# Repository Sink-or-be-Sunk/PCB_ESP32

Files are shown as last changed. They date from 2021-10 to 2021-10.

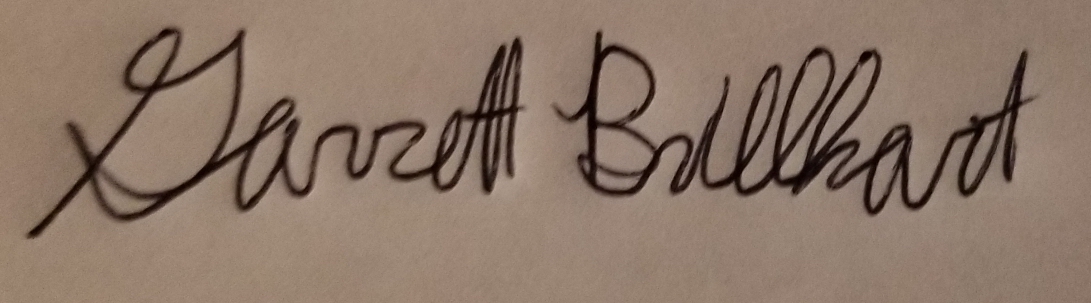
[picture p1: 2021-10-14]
assets/Garrett.jpeg

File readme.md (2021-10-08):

# Sink or be Sunk Hardware

This project contains the KiCAD PCB and auxiliary hardware needed for physical gameplay.

## Helpful Notes

### Nested Sheets

In KiCAD you can use a neat feature to split your project into multiple files. This not only helps to reduce cluter on one single diagram, it also allows for reuse of a common schematic element.

For this project specifically, the Grid.sch file can be reused for both the top (attack) grid and the bottom (ship positioning) grid.

`Hierarchical Labels` - KiCAD allows you to place a label on a nested sheet that can be viewed by the parenet sheet. Ex: you place a label on the STM32 Sheet and you can connect to it from the Main Layout schematic.

- Locate the `Hierarchical Labels` button on the right hand toolbar in kicad to place a label in a child sheet.
  - See section A4 of the STM32 Sheet
- Navigate back to the parent sheet and right click on the child sheet where you jused added the label
- Select the `import sheet pins` option
  - NOTE that you will have to do this for every new pin that you add to the child sheet, kinda repetative if you have a bunch of heirarchical labels...

`ESP32 Reference Design` - Adafruit produced a reference/dev board for the ESP32. They have great documentation on the device and are generous enough to include images of their schematic. This is a good place to start for our design. See the [Adafruit Website](https://learn.adafruit.com/adafruit-huzzah32-esp32-feather/downloads) for details.

#### PCB Updates to PCB_ESP32

I added a new branch with a new file "Main", containing all updated symbol and footprint libraries. There appears to be an issue between KiCad's footprint libraries in Version 4 and 5.0+. I believe I resolved this issue, let me know if you're still missing access to certain footprints. 

Other than that, I think this is a start. One great thing about our Main PCB is that the dimensions on it are much more flexible than the Row PCBs. If we need more room, we can make the board longer (wider will start to run into the grid). 

Some things to think about:
- USB to Serial: Where is the most convenient place for the plug? 
- What are the repercussions of placing the speaker next to the motor? 
- Where on the exterior of the board should the speaker knob/reset button go, without being bumped or in the way?

There's plenty of work left, but this is the start!

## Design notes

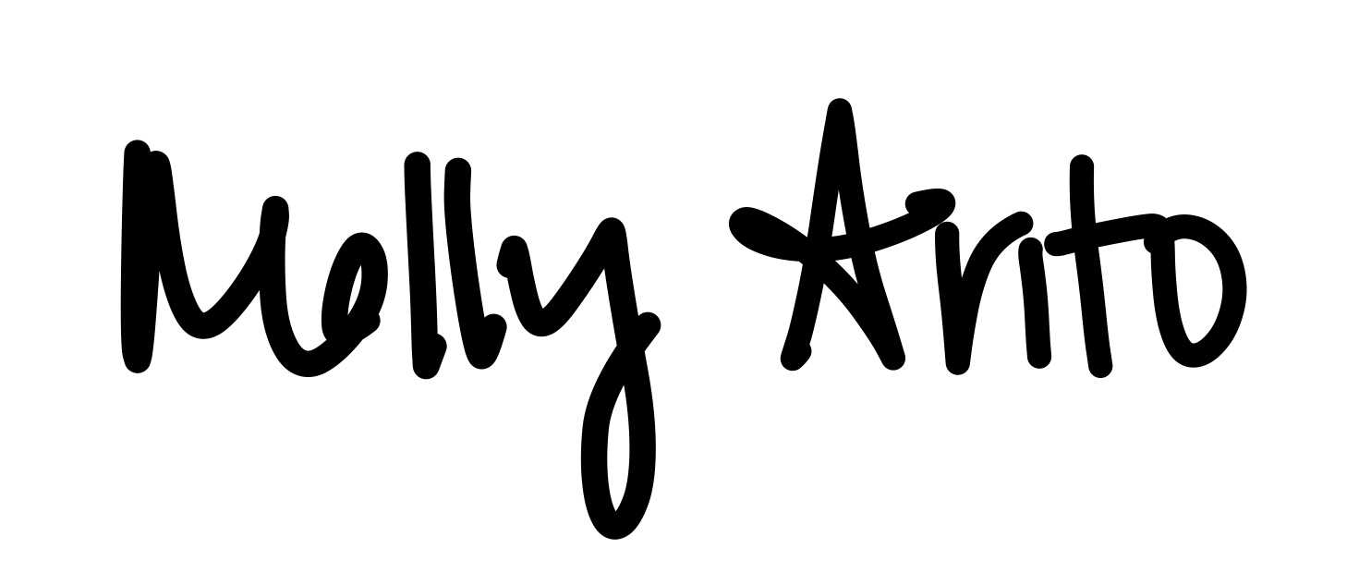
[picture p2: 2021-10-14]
assets/Molly.PNG

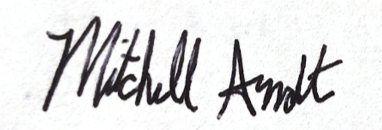
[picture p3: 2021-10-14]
assets/Mitch.png

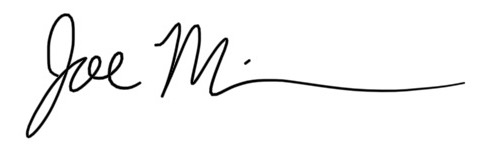
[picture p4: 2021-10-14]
assets/Joe.jpeg

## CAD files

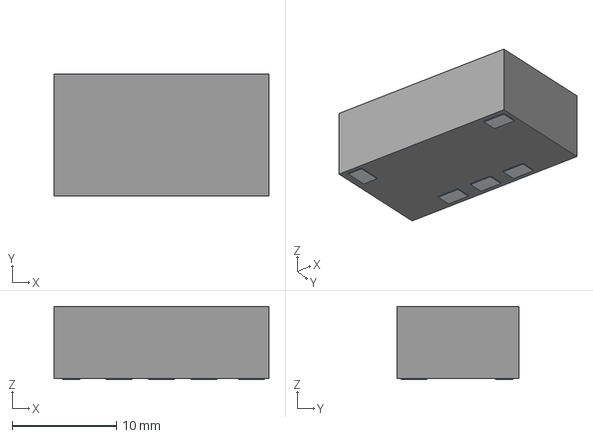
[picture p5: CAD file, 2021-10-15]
models/DNT04S0A0S03NFA.stp
20.6 x 11.7 x 7.00 mm
Pins

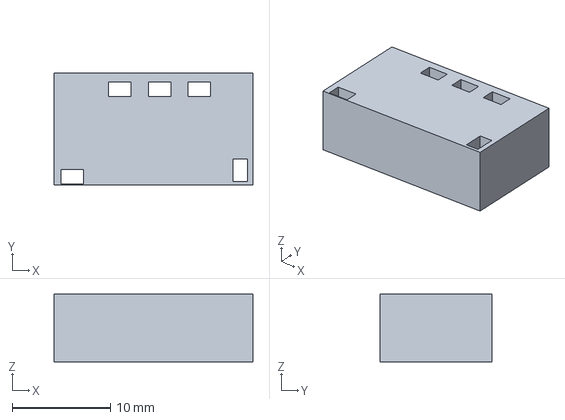
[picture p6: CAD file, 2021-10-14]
models/Regulator.step
20.3 x 11.4 x 6.90 mm

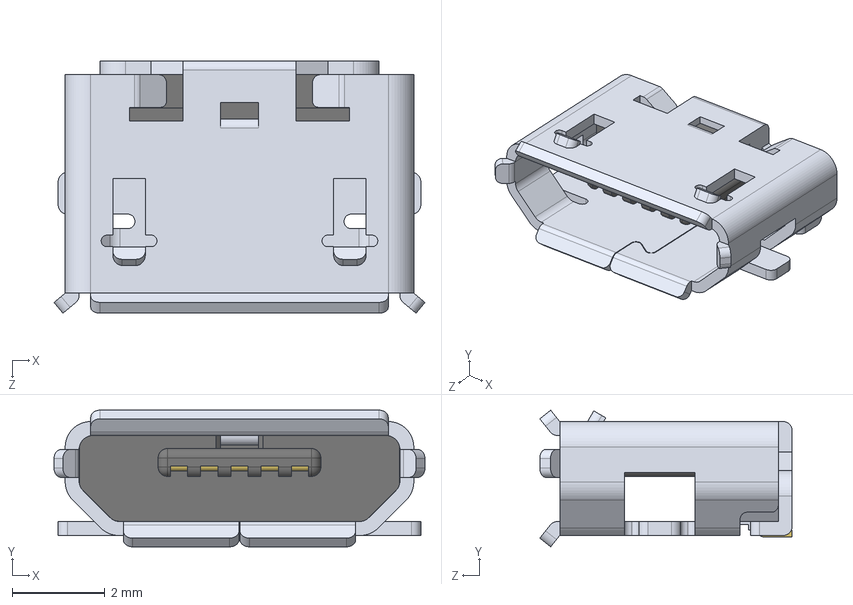
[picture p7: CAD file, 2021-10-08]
models/micro_usb.STEP
7.98 x 2.94 x 5.43 mm

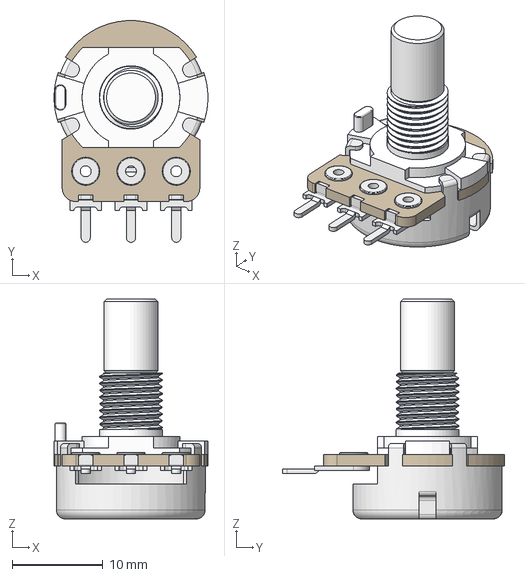
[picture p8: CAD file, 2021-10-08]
models/POT.step
17.0 x 24.5 x 24.3 mm

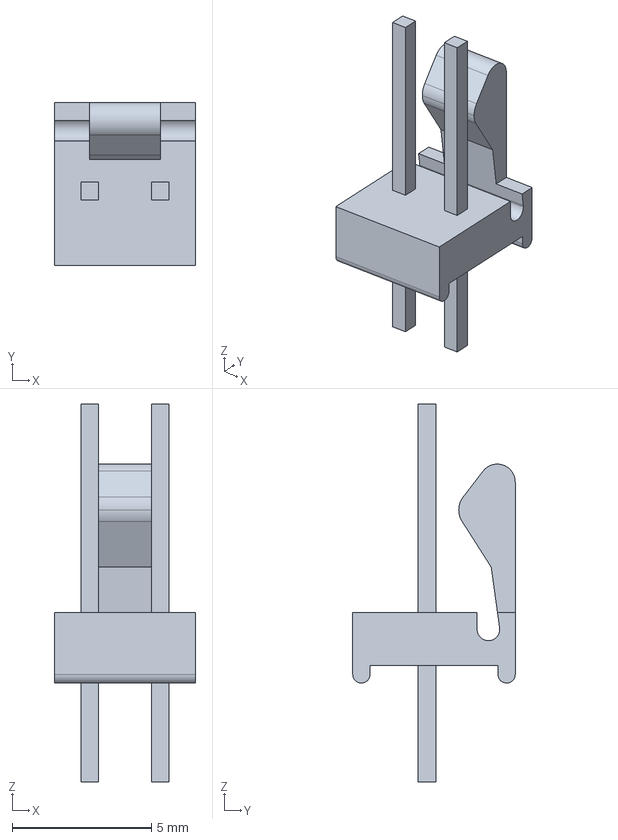
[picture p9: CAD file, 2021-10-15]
models/640456-2.step
5.08 x 5.84 x 13.6 mm

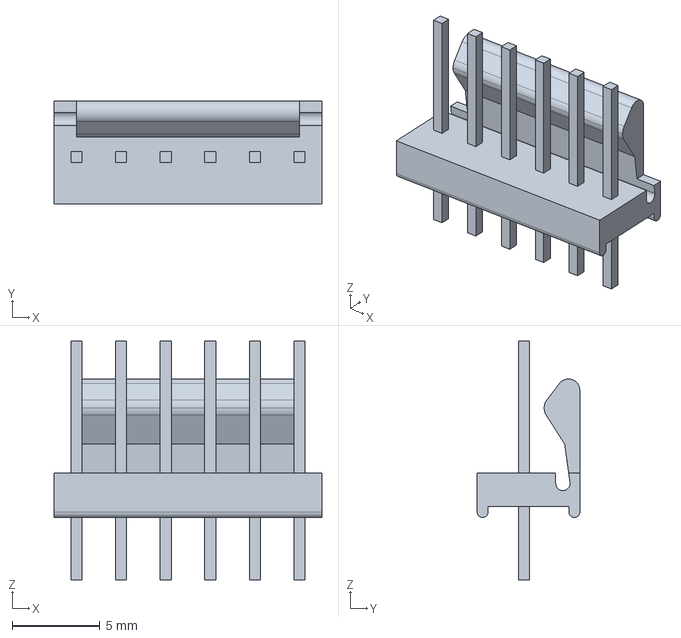
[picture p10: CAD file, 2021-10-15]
models/640456-6.step
15.2 x 5.84 x 13.6 mm

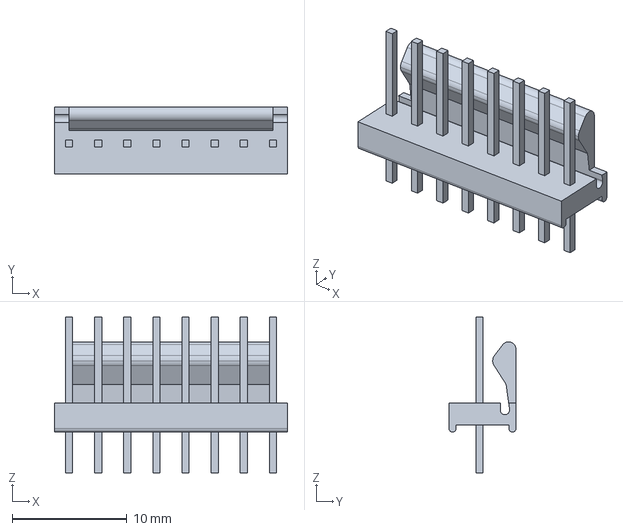
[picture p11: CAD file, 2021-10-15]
models/640456-8.step
20.3 x 5.84 x 13.6 mm

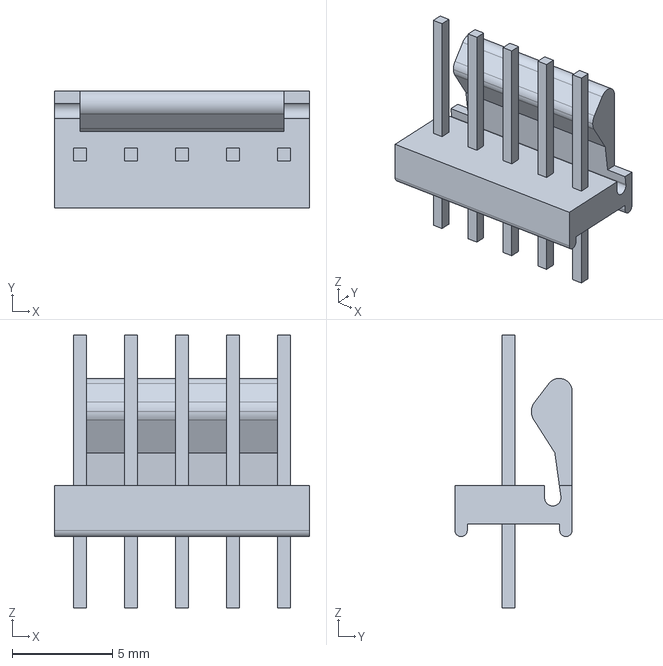
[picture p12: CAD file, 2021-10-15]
models/640456-5.step
12.7 x 5.84 x 13.6 mm

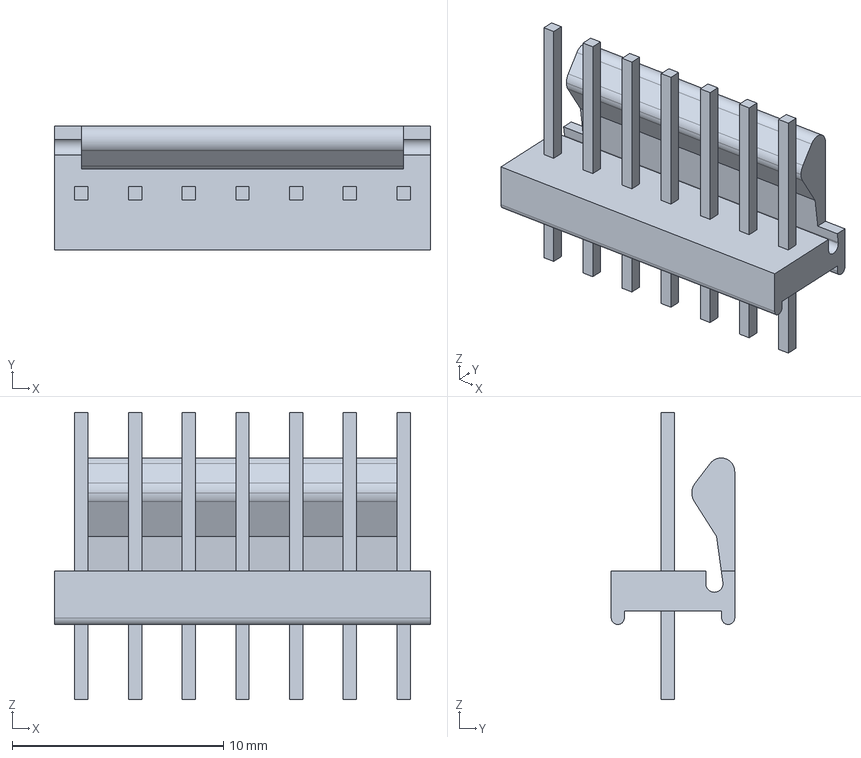
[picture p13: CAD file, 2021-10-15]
models/640456-7.step
17.8 x 5.84 x 13.6 mm

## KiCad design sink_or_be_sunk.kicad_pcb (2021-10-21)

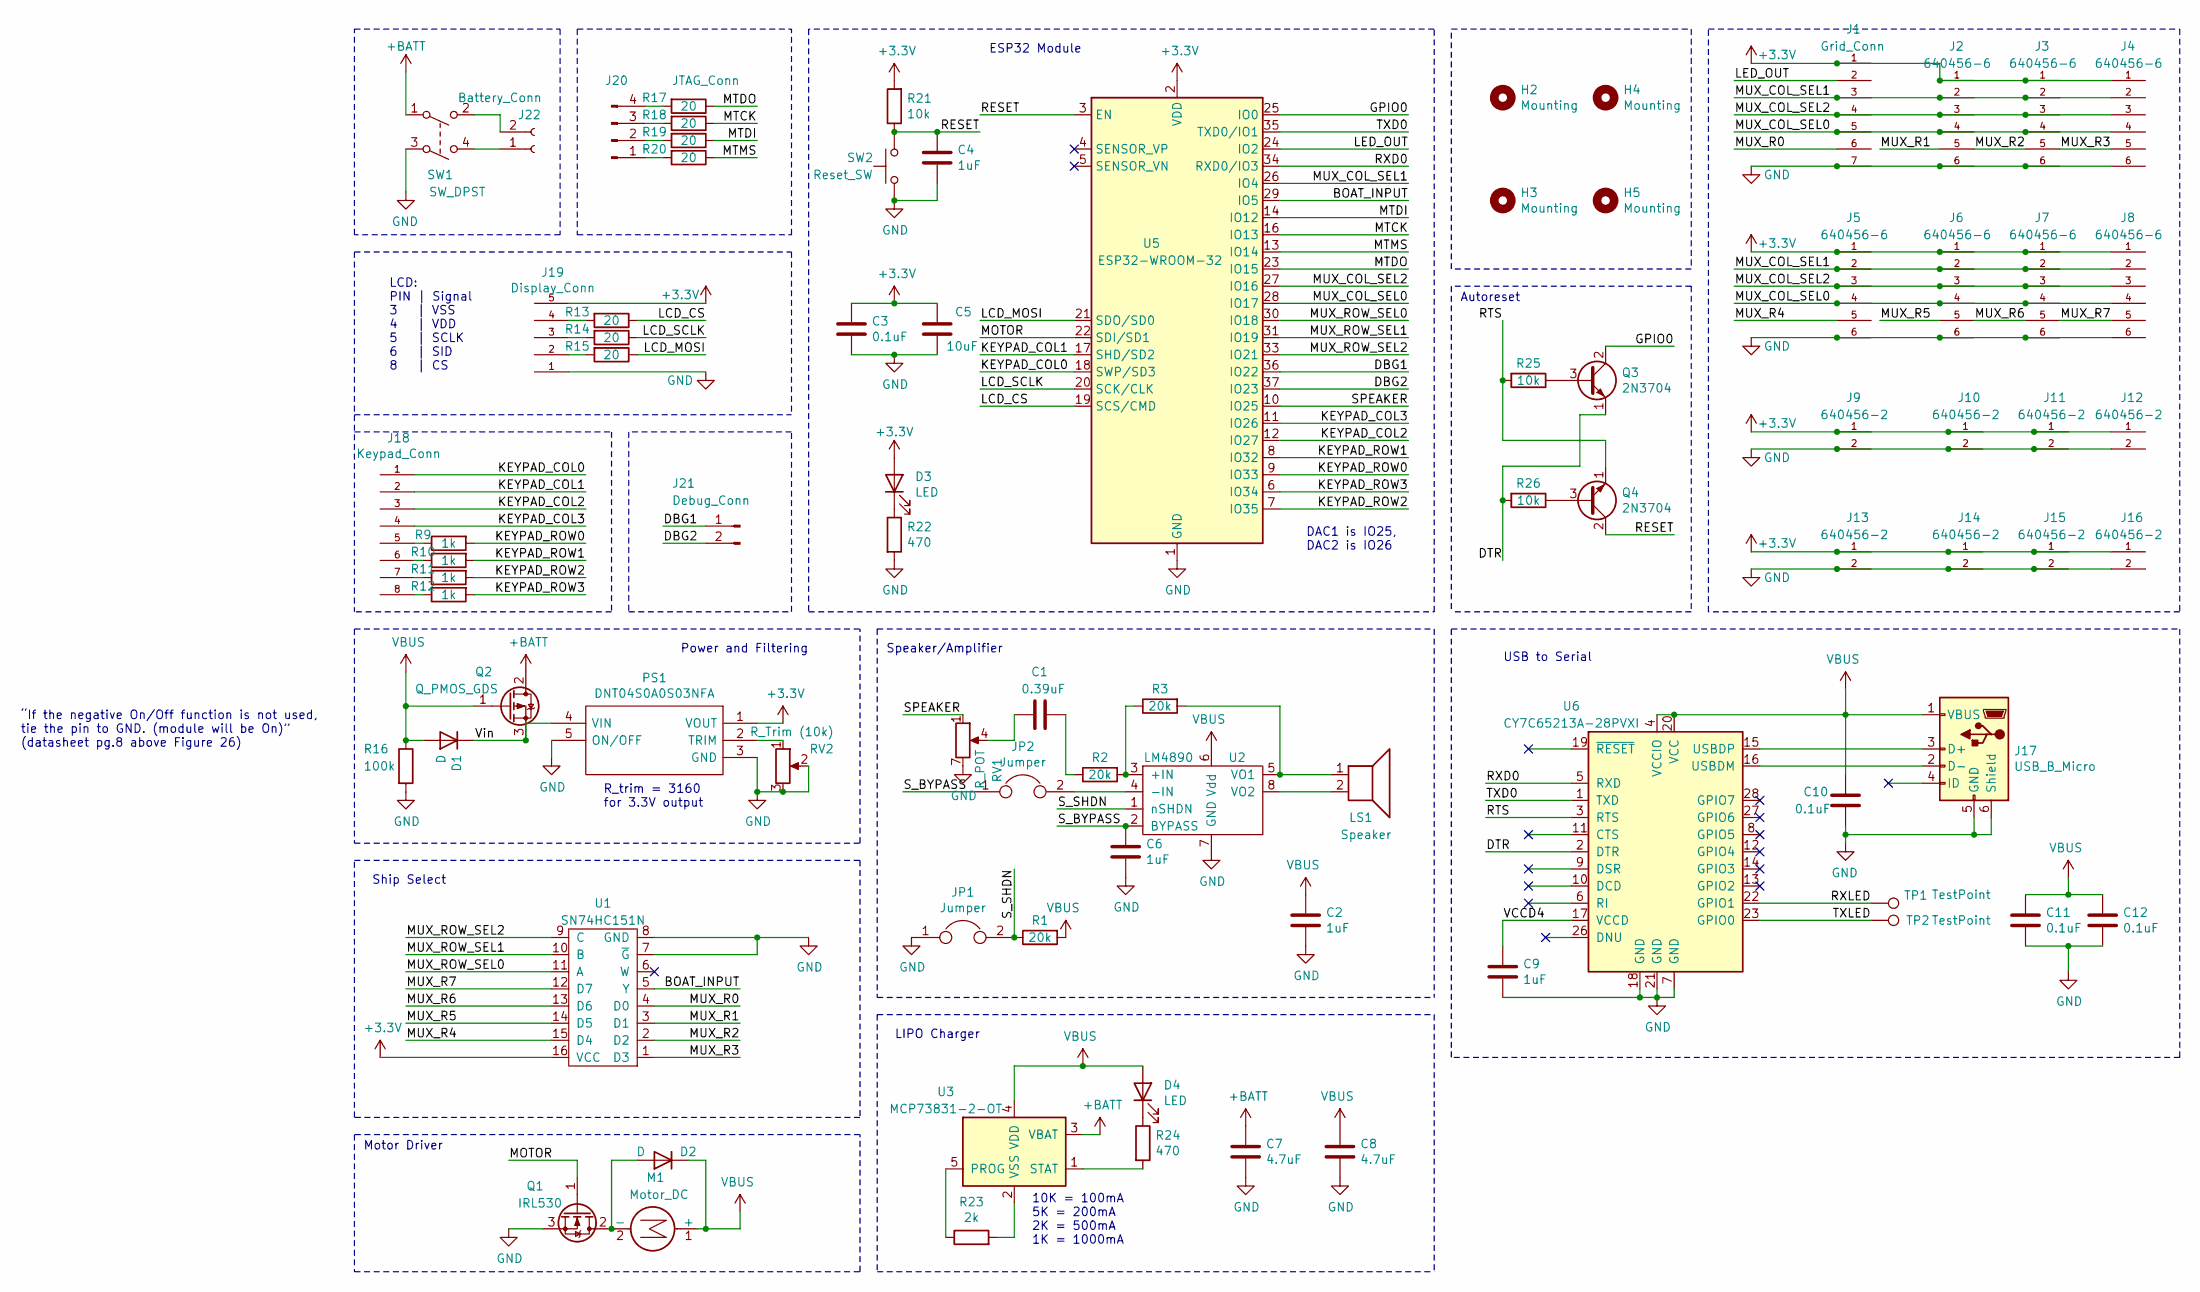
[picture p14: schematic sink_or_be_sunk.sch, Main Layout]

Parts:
C1: 0.39uF; C_0805_2012Metric_Pad1.18x1.45mm_HandSolder
C2, C4, C6: 1uF; C_0805_2012Metric_Pad1.18x1.45mm_HandSolder
C3, C10, C11, C12: 0.1uF; C_0805_2012Metric_Pad1.15x1.40mm_HandSolder
C5: 10uF; CP_Radial_D5.0mm_P2.50mm
C7, C8: 4.7uF; CP_Radial_D5.0mm_P2.50mm
C9: 1uF; C_0805_2012Metric_Pad1.15x1.40mm_HandSolder
D1, D2: D; D_A-405_P7.62mm_Horizontal
D3, D4: LED; LED_D3.0mm
H2, H3, H4, H5: Mounting; MountingHole_3.2mm_M3
J1: Grid_Conn; TE_640456-7
J2, J3, J4, J5, J6, J7, J8: 640456-6; TE_640456-6
J9, J10, J11, J12, J13, J14, J15, J16: 640456-2; TE_640456-2
J17: USB_B_Micro; USB_Micro_B_Female_Vert_1051330001
J18: Keypad_Conn; TE_640456-8
J19: Display_Conn; TE_640456-5
J20: JTAG_Conn; PinHeader_1x04_P2.54mm_Vertical
J21: Debug_Conn; PinHeader_1x02_P2.54mm_Vertical
J22: Battery_Conn; JST_PH_S2B-PH-K_1x02_P2.00mm_Horizontal
JP1, JP2: Jumper; PinHeader_1x02_P2.54mm_Vertical
LS1: Speaker; TE_640456-2
M1: Motor_DC; TE_640456-2
PS1: DNT04S0A0S03NFA; Mouser Part Number 108-DNT04S0A0S03NFA
Q1: IRL530; TO-220-3_Vertical
Q2: Q_PMOS_GDS; TO-251-3-1EP_Horizontal_TabDown
Q3, Q4: 2N3704; TO-92
R1, R2, R3: 20k; R_0805_2012Metric_Pad1.20x1.40mm_HandSolder
R9, R10, R11: 1k; R_0805_2012Metric_Pad1.20x1.40mm_HandSolder
R12: 1k; R_0805_2012Metric_Pad1.15x1.40mm_HandSolder
R13, R14, R15, R17, R18, R19, R20: 20; R_0805_2012Metric_Pad1.20x1.40mm_HandSolder
R16: 100k; R_0805_2012Metric_Pad1.15x1.40mm_HandSolder
R21, R25, R26: 10k; R_0805_2012Metric_Pad1.20x1.40mm_HandSolder
R22: 470; R_0805_2012Metric_Pad1.20x1.40mm_HandSolder
R23: 2k; R_0805_2012Metric_Pad1.15x1.40mm_HandSolder
R24: 470; R_0805_2012Metric_Pad1.15x1.40mm_HandSolder
RV1: R_POT; PinHeader_1x07_P2.54mm_Vertical
RV2: R_Trim (10k); Potentiometer_Bourns_3266Y_Vertical
SW1: SW_DPST; PinHeader_1x04_P2.54mm_Vertical
SW2: Reset_SW; PinHeader_1x02_P2.54mm_Vertical
TP1, TP2: TestPoint; TestPoint_Plated_Hole_D2.0mm
U1: SN74HC151N; DIP-16_W10.16mm
U2: LM4890; TSSOP-8_3x3mm_P0.65mm
U3: MCP73831-2-OT; SOT-23-5
U5: ESP32-WROOM-32
U6: CY7C65213A-28PVXI; SSOP-28_5.3x10.2mm_P0.65mm

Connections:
+3V3: C3.1, C5.1, D3.2 (A), J1.1, J2.1, J3.1, J4.1, J5.1, J6.1, J7.1, J8.1, J9.1, J10.1, J11.1, J12.1, J13.1, J14.1, J15.1, J16.1, J19.5, PS1.1 (VOUT), R21.2, U1.16 (VCC), U5.2 (VDD)
+BATT: C7.1, Q2.2 (D), SW1.1, U3.3 (VBAT)
/BOAT_INPUT: U1.5 (Y), U5.29 (IO5)
/DBG1: J21.1, U5.36 (IO22)
/DBG2: J21.2, U5.37 (IO23)
/DTR: Q3.1 (E), R26.2, U6.2 (DTR)
/GPIO0: Q3.2 (C), U5.25 (IO0)
/KEYPAD_COL0: J18.1, U5.18 (SWP/SD3)
/KEYPAD_COL1: J18.2, U5.17 (SHD/SD2)
/KEYPAD_COL2: J18.3, U5.12 (IO27)
/KEYPAD_COL3: J18.4, U5.11 (IO26)
/KEYPAD_ROW0: R9.2, U5.9 (IO33)
/KEYPAD_ROW1: R10.2, U5.8 (IO32)
/KEYPAD_ROW2: R11.2, U5.7 (IO35)
/KEYPAD_ROW3: R12.2, U5.6 (IO34)
/LCD_CS: R13.1, U5.19 (SCS/CMD)
/LCD_MOSI: R15.1, U5.21 (SDO/SD0)
/LCD_SCLK: R14.1, U5.20 (SCK/CLK)
/LED_OUT: J1.2, U5.24 (IO2)
/MOTOR: Q1.1 (G), U5.22 (SDI/SD1)
/MTCK: R18.1, U5.16 (IO13)
/MTDI: R19.1, U5.14 (IO12)
/MTDO: R17.1, U5.23 (IO15)
/MTMS: R20.1, U5.13 (IO14)
/MUX_COL_SEL0: J1.5, J2.4, J3.4, J4.4, J5.4, J6.4, J7.4, J8.4, U5.28 (IO17)
/MUX_COL_SEL1: J1.3, J2.2, J3.2, J4.2, J5.2, J6.2, J7.2, J8.2, U5.26 (IO4)
/MUX_COL_SEL2: J1.4, J2.3, J3.3, J4.3, J5.3, J6.3, J7.3, J8.3, U5.27 (IO16)
/MUX_R0: J1.6, U1.4 (D0)
/MUX_R1: J2.5, U1.3 (D1)
/MUX_R2: J3.5, U1.2 (D2)
/MUX_R3: J4.5, U1.1 (D3)
/MUX_R4: J5.5, U1.15 (D4)
/MUX_R5: J6.5, U1.14 (D5)
/MUX_R6: J7.5, U1.13 (D6)
/MUX_R7: J8.5, U1.12 (D7)
/MUX_ROW_SEL0: U1.11 (A), U5.30 (IO18)
/MUX_ROW_SEL1: U1.10 (B), U5.31 (IO19)
/MUX_ROW_SEL2: U1.9 (C), U5.33 (IO21)
/RESET: C4.1, Q4.2 (C), R21.1, SW2.2, U5.3 (EN)
/RTS: Q4.1 (E), R25.2, U6.3 (RTS)
/RXD0: U5.34 (RXD0/IO3), U6.5 (RXD)
/RXLED: TP1.1, U6.22 (GPIO1)
/SPEAKER: RV1.1, U5.10 (IO25)
/S_BYPASS: C6.1, JP2.1, U2.2 (BYPASS)
/S_SHDN: JP1.2, R1.1, U2.1 (nSHDN)
/TXD0: U5.35 (TXD0/IO1), U6.1 (TXD)
/TXLED: TP2.1, U6.23 (GPIO0)
/VCCD4: C9.1, U6.17 (VCCD)
/Vin: D1.1 (K), PS1.4 (VIN), Q2.3 (S)
GND: C2.2, C3.2, C4.2, C5.2, C6.2, C7.2, C8.2, C9.2, C10.2, C11.2, C12.2, J1.7, J2.6, J3.6, J4.6, J5.6, J6.6, J7.6, J8.6, J9.2, J10.2, J11.2, J12.2, J13.2, J14.2, J15.2, J16.2, J17.5 (GND), J17.6 (Shield), J19.1, JP1.1, PS1.3 (GND), PS1.5 (ON/OFF), Q1.3 (S), R16.2, R22.2, RV1.7, RV2.2, RV2.3, SW1.3, SW2.1, U1.7 (~G), U1.8 (GND), U2.7 (GND), U5.1 (GND), U5.15 (GND), U5.38 (GND), U5.39 (GND), U6.7 (GND), U6.18 (GND), U6.21 (GND)
unnamed: C1.1, RV1.4
unnamed: C1.2, R2.1
unnamed: D2.2 (A), M1.2 (-), Q1.2 (D)
unnamed: D3.1 (K), R22.1
unnamed: D4.1 (K), R24.1
unnamed: J17.2 (D-), U6.16 (USBDM)
unnamed: J17.3 (D+), U6.15 (USBDP)
unnamed: J18.5, R9.1
unnamed: J18.6, R10.1
unnamed: J18.7, R11.1
unnamed: J18.8, R12.1
unnamed: J19.2, R15.2
unnamed: J19.3, R14.2
unnamed: J19.4, R13.2
unnamed: J20.1, R20.2
unnamed: J20.2, R19.2
unnamed: J20.3, R18.2
unnamed: J20.4, R17.2
unnamed: J22.1, SW1.4
unnamed: J22.2, SW1.2
unnamed: JP2.2, U2.4 (-IN)
unnamed: LS1.1, R3.2, U2.5 (VO1)
unnamed: LS1.2, U2.8 (VO2)
unnamed: PS1.2 (TRIM), RV2.1
unnamed: Q3.3 (B), R25.1
unnamed: Q4.3 (B), R26.1
unnamed: R2.2, R3.1, U2.3 (+IN)
unnamed: R23.1, U3.5 (PROG)
unnamed: R23.2, U3.2 (VSS)
unnamed: R24.2, U3.1 (STAT)
VBUS: C2.1, C8.1, C10.1, C11.1, C12.1, D1.2 (A), D2.1 (K), D4.2 (A), J17.1 (VBUS), M1.1 (+), Q2.1 (G), R1.2, R16.1, U2.6 (Vdd), U3.4 (VDD), U6.4 (VCCIO), U6.20 (VCC)

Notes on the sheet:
LCD: PIN | Signal 3 | VSS 4 | VDD 5 | SCLK 6 | SID 8 | CS
10K = 100mA 5K = 200mA 2K = 500mA 1K = 1000mA
USB to Serial
ESP32 Module
Motor Driver
Autoreset
LIPO Charger
Ship Select
Speaker/Amplifier
DAC1 is IO25, DAC2 is IO26
“If the negative On/Off function is not used, tie the pin to GND. (module will be On)” (datasheet pg.8 above Figure 26)
R_trim = 3160 for 3.3V output
Power and Filtering

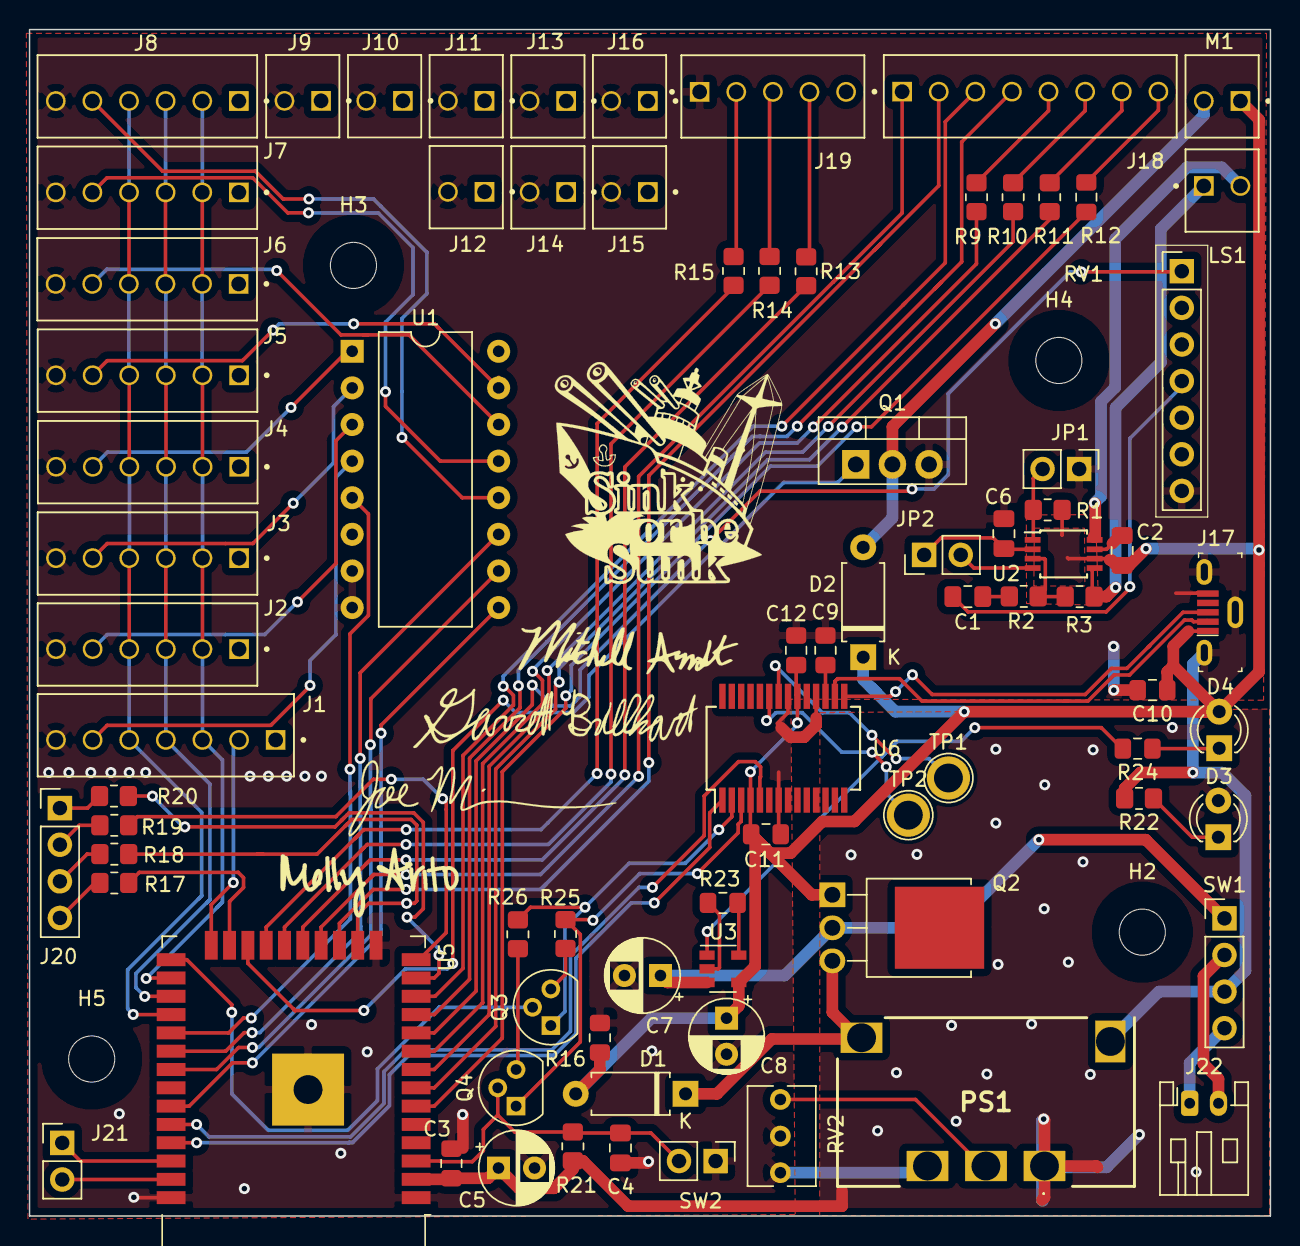
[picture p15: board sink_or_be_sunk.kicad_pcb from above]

Board: 2 copper layers, 86.1 x 82.3 mm, 83 parts (0 on the bottom side), 81 nets.

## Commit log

2021-09-01 imported ece 362 project and added template for main schematic
    [ECX-.327-CDX-1293.step, ESP32.sch, Grid.sch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]
2021-09-01 updated the readme and added example of heirarchical labels
    [STM32.sch, sink_or_be_sunk.sch]
2021-09-01 addes esp32 info to readme
2021-09-17 removed unneeded sheets and added speaker sheet/circuit
    [ESP32.sch, Grid.sch, STM32.sch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]
2021-09-22 added all pin definitions
    [sink_or_be_sunk.sch]
2021-09-30 first iteration of main pcb
    [Boat_Mux.sch, Grid_Rows.sch, Keypad.sch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]
2021-09-30 cleaned up files
    [Boat_Mux.sch, Grid_Rows.sch, Keypad.sch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]
2021-09-30 check speaker pot footprint
    [sink_or_be_sunk.sch]
2021-09-30 added some notes/todos on schematic
    [sink_or_be_sunk.sch]
2021-10-01 updated todo
    [sink_or_be_sunk.sch]
2021-10-01 made some tweaks to usb/power circuits
    [sink_or_be_sunk.sch]
2021-10-01 ready to put on homepage
    [sink_or_be_sunk.sch]
2021-10-03 updated serial programming circuitry
    [sink_or_be_sunk.sch]
2021-10-03 updated todos with 5V motor requirement
    [sink_or_be_sunk.sch]
2021-10-06 Check Main for PCB updates
    [Main.kicad_pcb, Main.sch, sink_or_be_sunk.kicad_pcb]
2021-10-06 Continued progress
    [Main.kicad_pcb, Main.sch]
2021-10-06 cleaned up project
    [Boat_Mux.sch, ECX-.327-CDX-1293.step, Grid_Rows.sch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]
2021-10-06 added electrical isoltion switch
    [sink_or_be_sunk.kicad_pcb, sink_or_be_sunk.sch]
2021-10-06 redo of layout and minor circuit updates
    [sink_or_be_sunk.kicad_pcb, sink_or_be_sunk.sch]
2021-10-07 minor updates to board settings
    [sink_or_be_sunk.kicad_pcb]
2021-10-07 10/7 organizing ratsnest more
    [sink_or_be_sunk.kicad_pcb, sink_or_be_sunk.sch]
2021-10-07 updated with todos from talk with prof
    [sink_or_be_sunk.kicad_pcb, sink_or_be_sunk.sch]
2021-10-08 finished routing power and programming circuit
    [sink_or_be_sunk.kicad_pcb, sink_or_be_sunk.sch]
2021-10-08 before pin shift
    [sink_or_be_sunk.kicad_pcb]
2021-10-08 finsihed routing mux
    [sink_or_be_sunk.kicad_pcb, sink_or_be_sunk.sch]
2021-10-08 fixed error in grid conn sch
    [sink_or_be_sunk.kicad_pcb, sink_or_be_sunk.sch]
2021-10-08 all components placed, need to finish up the routing
    [POT.step, sink_or_be_sunk.kicad_pcb, sink_or_be_sunk.sch]
2021-10-08 finished layout, some drc errors that need fixing
    [sink_or_be_sunk.kicad_pcb, sink_or_be_sunk.sch]
2021-10-08 added edge cuts
    [sink_or_be_sunk.kicad_pcb]
2021-10-09 connector updates
    [sink_or_be_sunk.kicad_pcb, sink_or_be_sunk.sch]
2021-10-09 left off shrinking width
    [sink_or_be_sunk.kicad_pcb, sink_or_be_sunk.sch]
2021-10-10 finsihed 79x85mm layout
    [sink_or_be_sunk.kicad_pcb]
2021-10-10 added some notes/questions to sch/pcb
    [sink_or_be_sunk.kicad_pcb, sink_or_be_sunk.sch]
2021-10-13 added new switching regulator footprint
    [sink_or_be_sunk.kicad_pcb, sink_or_be_sunk.sch]
2021-10-13 before switching pmos
    [Regulator.step, sink_or_be_sunk.kicad_pcb, sink_or_be_sunk.sch]
2021-10-13 updated switching regulator and pmos
    [sink_or_be_sunk.kicad_pcb, sink_or_be_sunk.sch]
2021-10-13 added logo to board
    [sink_or_be_sunk.kicad_pcb, sink_or_be_sunk.sch]
2021-10-14 added team signatures to the board
    [sink_or_be_sunk.kicad_pcb]
2021-10-14 updated trace widths
    [sink_or_be_sunk.kicad_pcb]
2021-10-14 updated edge cuts
    [sink_or_be_sunk.kicad_pcb]
2021-10-14 updated back copper to power plane
    [sink_or_be_sunk.kicad_pcb]
2021-10-15 added new connectors
    [640456-2.step, 640456-5.step, 640456-6.step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]
2021-10-15 cleaned up footprints
    [640456-2.step, 640456-5.step, 640456-6.step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]
2021-10-15 updated library with footprints
    [sink_or_be_sunk.sch]
2021-10-15 brought over board from regulator
    [sink_or_be_sunk.kicad_pcb, sink_or_be_sunk.sch]
2021-10-15 updated with new regulator symbol
    [sink_or_be_sunk.sch]
2021-10-15 brought over regulator footprint
    [DNT04S0A0S03NFA.stp, sink_or_be_sunk.sch]
2021-10-15 merged connectors and regulator footprint
    [sink_or_be_sunk.kicad_pcb, sink_or_be_sunk.sch]
2021-10-16 updated dimensions
    [sink_or_be_sunk.kicad_pcb]
2021-10-18 fixed issue with attack connector labels
    [sink_or_be_sunk.kicad_pcb]
2021-10-19 updated hole footprint, power plane adjustments
    [sink_or_be_sunk.kicad_pcb, sink_or_be_sunk.sch]
2021-10-21 updated schematic for new amp
    [sink_or_be_sunk.kicad_pcb, sink_or_be_sunk.sch]
2021-10-21 finished merge with amp
    [sink_or_be_sunk.kicad_pcb, sink_or_be_sunk.sch]
2021-10-21 finished routing with new circuit and added back silk screen
    [sink_or_be_sunk.kicad_pcb, sink_or_be_sunk.sch]
2021-10-21 updated silkscreen refs for new amp circuit
    [sink_or_be_sunk.kicad_pcb]
